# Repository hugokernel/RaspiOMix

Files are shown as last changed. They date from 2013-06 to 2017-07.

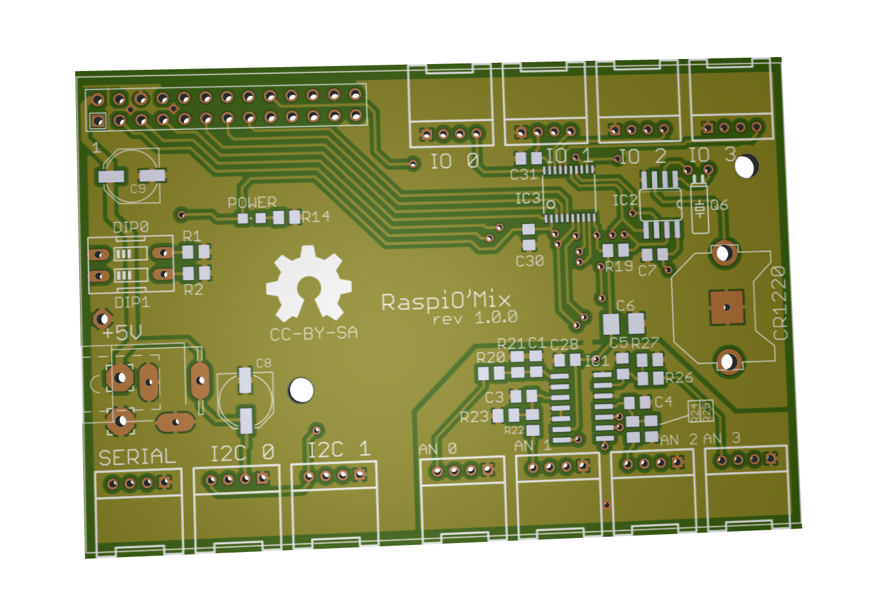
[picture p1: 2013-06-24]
export/1.0.0/images/gerber.png

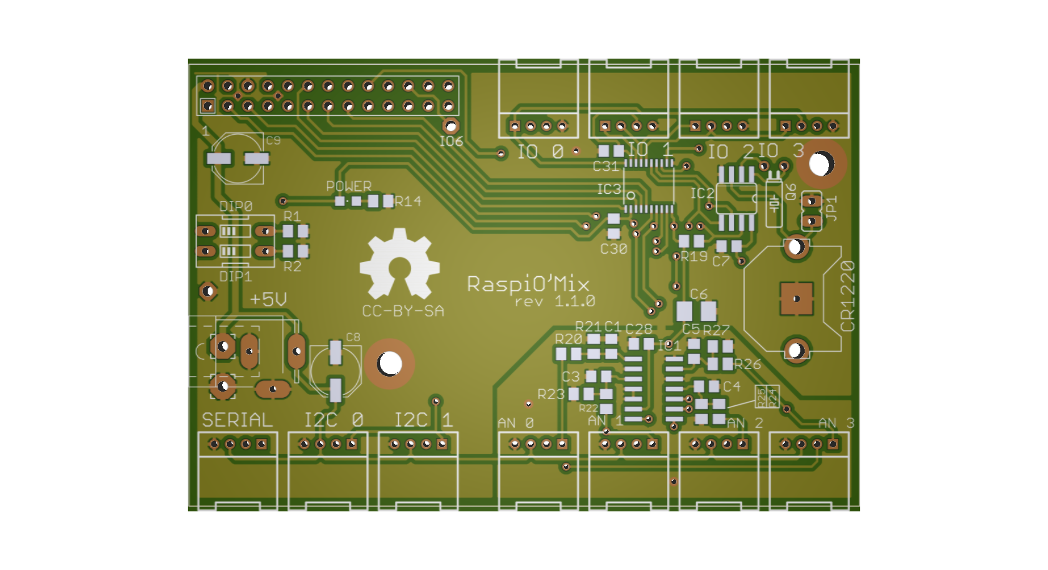
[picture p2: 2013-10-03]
export/1.1.0/images/gerber.png

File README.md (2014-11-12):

RaspiOMix
=========

A RaspberryPi board with 5V tolerance and Grove compatible.

Specifications
--------------

- 4 general 5V tolerant input / output
- 4 analog input, 0-5V, 18 bit resolution (MCP3424)
- 2 digital input via DIP switch
- Real Time Clock with battery backup (DS1307)
- 2 I2C external connector
- 1 serial external connector
- Power input via jack

Python example :

    >>> from raspiomix import Raspiomix
    >>> r = Raspiomix()
    >>> r.readRtc()
    2014-11-12T20:41:26
    >>> print(r.readAdc(0))
    [4.0669732000000005]
    >>>print(r.readAdc((0, 1, 2, 3)))
    [4.066934600000001, 0.010923800000000001, 0.08515160000000001, 0.2866822]

--

Une carte fille pour RaspberryPi avec entrées / sorties tolérantes au 5V et des connecteurs compatible Grove.

Caractéristiques
----------------

- 4 entrées / sorties tolérantes 5V
- 4 entrées analogiques, 0-5V, 18 bits de résolution (MCP3424)
- 2 entrées numériques via DIP switch
- Horloge temps réel avec batterie de sauvegarde (DS1307)
- 2 connecteurs pour I2C
- 1 connecteur pour communication série
- Alimentation via jack

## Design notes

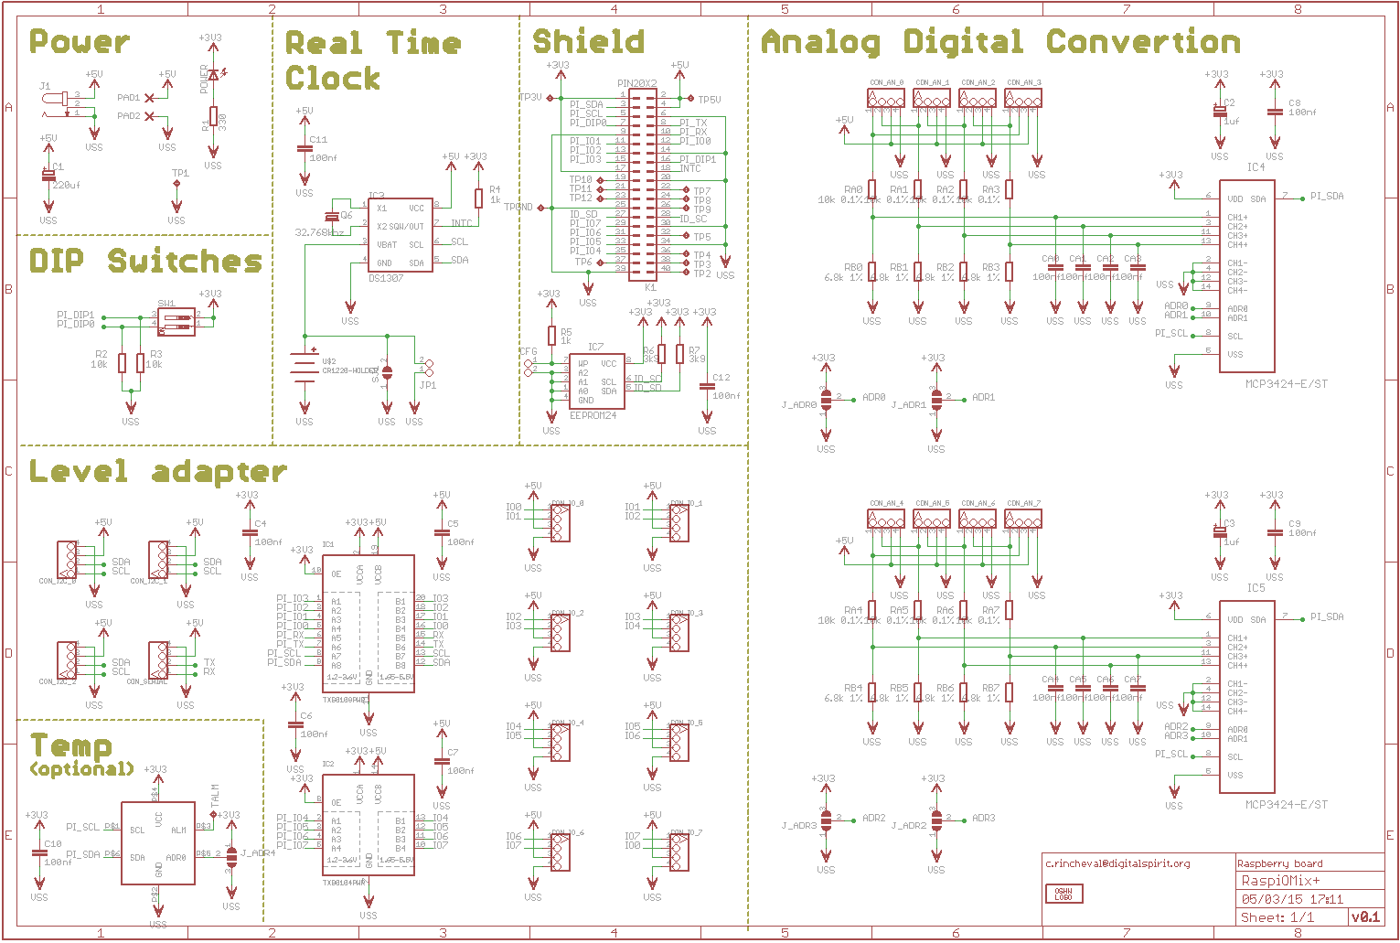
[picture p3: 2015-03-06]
export/2.0.0/images/schema.png

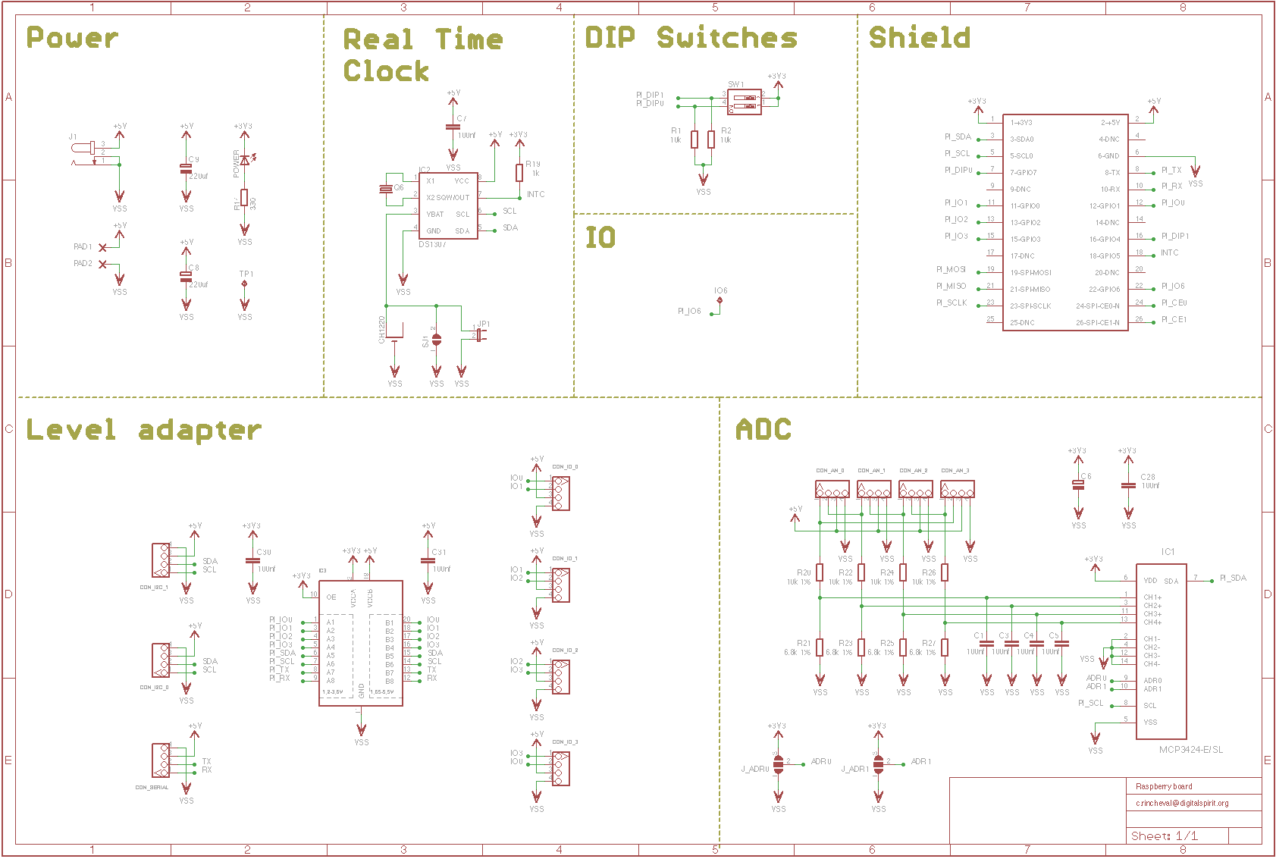
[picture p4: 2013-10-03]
export/1.1.0/images/schema.png

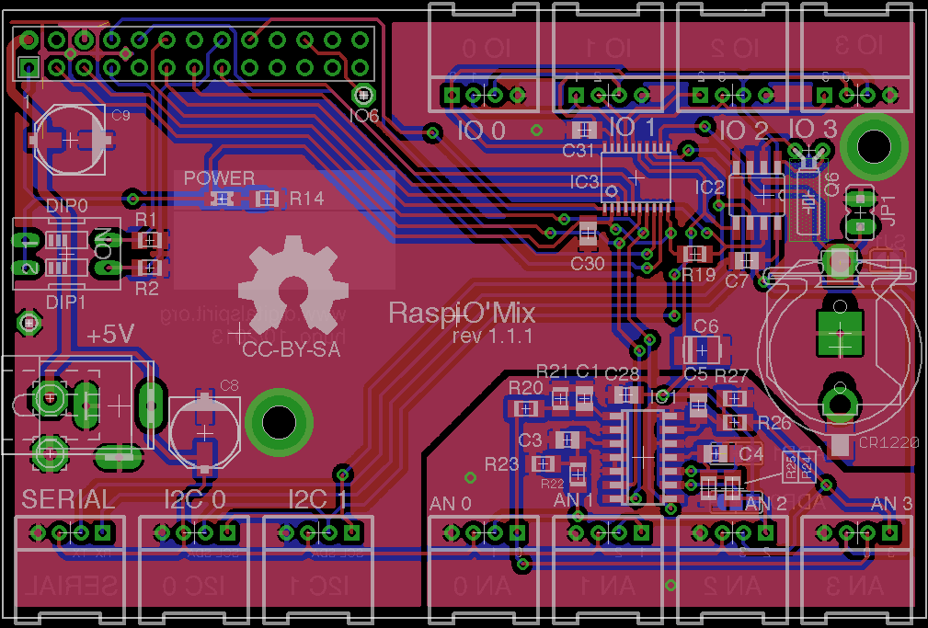
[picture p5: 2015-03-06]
export/1.1.1/images/pcb.png

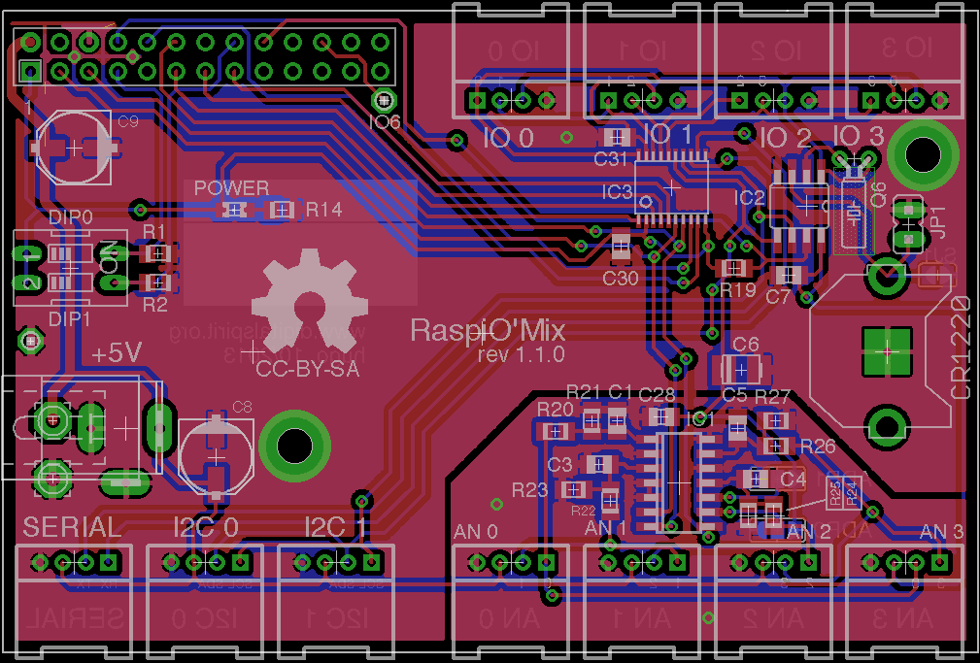
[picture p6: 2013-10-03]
export/1.1.0/images/pcb.png

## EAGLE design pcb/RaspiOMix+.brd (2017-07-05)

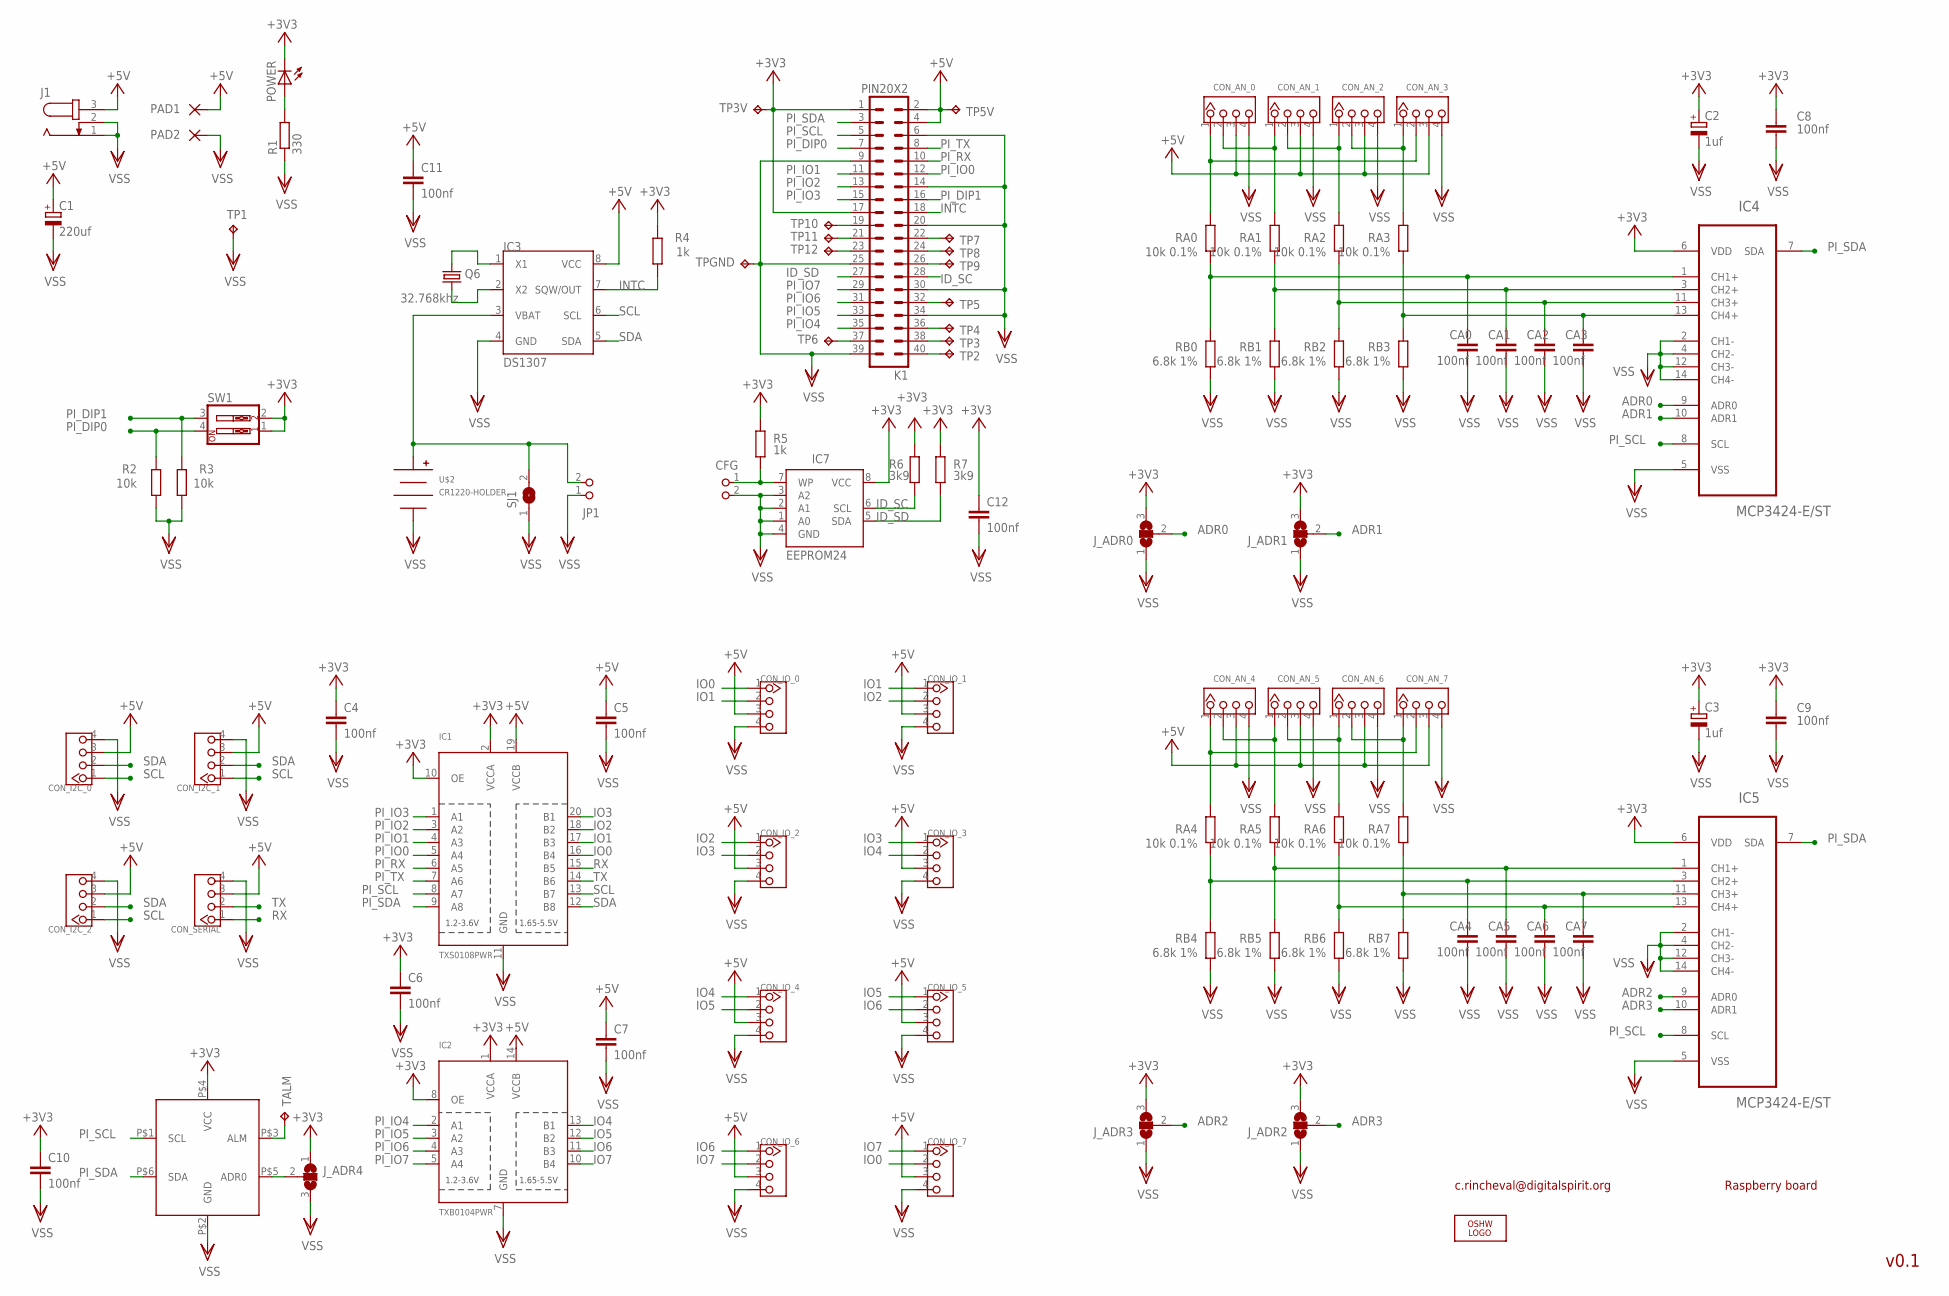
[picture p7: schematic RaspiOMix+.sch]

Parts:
C1: 220uf; PANASONIC_D
C2, C3: 1uf; B/3528-21R
C4, C5, C6, C7, C8, C9, C10, C11: 100nf; C0805
C12: 100nf; C0805K
CA0, CA1, CA2, CA3, CA4, CA5, CA6, CA7: 100nf; C0805
CFG: PIN2_100; PIN_W_2
CON_AN_0, CON_AN_1, CON_AN_2, CON_AN_3, CON_AN_4, CON_AN_5, CON_AN_6, CON_AN_7: TWIG-4P-2.0-2.0; 4P-2.0
CON_I2C_0, CON_I2C_1, CON_I2C_2: TWIG-4P-2.0-2.0; 4P-2.0
CON_IO_0, CON_IO_1, CON_IO_2, CON_IO_3, CON_IO_4, CON_IO_5, CON_IO_6, CON_IO_7: TWIG-4P-2.0-2.0; 4P-2.0
CON_SERIAL: TWIG-4P-2.0-2.0; 4P-2.0
IC1: TXS0108PWR; TSSOP20
IC2: TXB0104PWR; TSSOP14
IC3: DS1307; SOIC-8
IC4, IC5: MCP3424-E/ST; SOP65P640X120-14N
IC6: TMP101; SOT23-6
IC7: EEPROM24; SOIC8
J1: JACK-PLUG0; SPC4077
JP1: PIN2_100; PIN_W_2
J_ADR0, J_ADR1, J_ADR2, J_ADR3, J_ADR4: SJ2W; SJ_2
K1: PIN20X2; PIN_20X2
LOGO1: OSHW_LOGO_FILLX0350-NT; OSHW_FILLX350_NOTEXT
PAD1, PAD2: WIREPAD3,17/1,3; 3,17/1,3
POWER: LEDCHIPLED_0805; CHIPLED_0805
Q6: 32.768khz; TC26H
R1: 330; M0805
R2, R3: 10k; M0805
R4: 1k; M0805
R5: 1k; M0805; TOLERANCE 5%
R6, R7: 3k9; M0805; TOLERANCE 5%
RA0, RA1, RA2, RA3, RA4, RA5, RA6, RA7: 10k 0.1%; M0805
RB0, RB1, RB2, RB3, RB4, RB5, RB6, RB7: 6.8k 1%; M0805
SJ1: SJ
SW1: SW_DIP-2; EDG-02
TALM: TPTP12R; TP12R
TP1: TPPAD1-13; P1-13
TP2, TP3, TP3V, TP4, TP5, TP5V, TP6, TP7, TP8, TP9, TP10, TP11, TP12: TPTP12R; TP12R
TPGND: TPTP12R; TP12R
U$2: CR1220-HOLDER; HARWIN-CR1220

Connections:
+3V3: C2.+, C3.+, C4.1, C6.1, C8.2, C9.2, C10.1, C12.1, IC1.2 (VCCA), IC1.10 (OE), IC2.1 (VCCA), IC2.8 (OE), IC4.6 (VDD), IC5.6 (VDD), IC6.P$4 (VCC), IC7.8 (VCC), J_ADR0.3, J_ADR1.3, J_ADR2.3, J_ADR3.3, J_ADR4.1, K1.1, K1.17, POWER.C, R4.2, R5.2, R6.2, R7.2, SW1.1, SW1.2, TP3V.TP
+5V: C1.+, C5.1, C7.1, C11.1, CON_AN_0.3, CON_AN_1.3, CON_AN_2.3, CON_AN_3.3, CON_AN_4.3, CON_AN_5.3, CON_AN_6.3, CON_AN_7.3, CON_I2C_0.3, CON_I2C_1.3, CON_I2C_2.3, CON_IO_0.3, CON_IO_1.3, CON_IO_2.3, CON_IO_3.3, CON_IO_4.3, CON_IO_5.3, CON_IO_6.3, CON_IO_7.3, CON_SERIAL.3, IC1.19 (VCCB), IC2.14 (VCCB), IC3.8 (VCC), J1.3, K1.2, K1.4, PAD1.1, TP5V.TP
ADR0: IC4.9 (ADR0), J_ADR0.2
ADR1: IC4.10 (ADR1), J_ADR1.2
ADR2: IC5.9 (ADR0), J_ADR3.2
ADR3: IC5.10 (ADR1), J_ADR2.2
AN0: CON_AN_0.1, CON_AN_3.2, RA0.2
AN1: CON_AN_0.2, CON_AN_1.1, RA1.2
AN2: CON_AN_1.2, CON_AN_2.1, RA2.2
AN3: CON_AN_2.2, CON_AN_3.1, RA3.2
AN4: CON_AN_4.1, CON_AN_7.2, RA4.2
AN5: CON_AN_4.2, CON_AN_5.1, RA5.2
AN6: CON_AN_5.2, CON_AN_6.1, RA6.2
AN7: CON_AN_6.2, CON_AN_7.1, RA7.2
ID_SC: IC7.6 (SCL), K1.28, R6.1
ID_SD: IC7.5 (SDA), K1.27, R7.1
INTC: IC3.7 (SQW/OUT), K1.18, R4.1
IO0: CON_IO_0.1, CON_IO_7.2, IC1.16 (B4)
IO1: CON_IO_0.2, CON_IO_1.1, IC1.17 (B3)
IO2: CON_IO_1.2, CON_IO_2.1, IC1.18 (B2)
IO3: CON_IO_2.2, CON_IO_3.1, IC1.20 (B1)
IO4: CON_IO_3.2, CON_IO_4.1, IC2.13 (B1)
IO5: CON_IO_4.2, CON_IO_5.1, IC2.12 (B2)
IO6: CON_IO_5.2, CON_IO_6.1, IC2.11 (B3)
IO7: CON_IO_6.2, CON_IO_7.1, IC2.10 (B4)
unnamed: K1.40, TP2.TP
unnamed: K1.38, TP3.TP
unnamed: CFG.1, IC7.7 (WP), R5.1
unnamed: CA3.1, IC4.13 (CH4+), RA3.1, RB3.2
unnamed: CA2.1, IC4.11 (CH3+), RA2.1, RB2.2
unnamed: CA1.1, IC4.3 (CH2+), RA1.1, RB1.2
unnamed: CA0.1, IC4.1 (CH1+), RA0.1, RB0.2
unnamed: CA7.1, IC5.11 (CH3+), RA7.1, RB7.2
unnamed: CA6.1, IC5.13 (CH4+), RA6.1, RB6.2
unnamed: CA5.1, IC5.1 (CH1+), RA5.1, RB5.2
unnamed: CA4.1, IC5.3 (CH2+), RA4.1, RB4.2
unnamed: K1.36, TP4.TP
unnamed: K1.32, TP5.TP
unnamed: K1.37, TP6.TP
unnamed: K1.22, TP7.TP
unnamed: K1.24, TP8.TP
unnamed: K1.26, TP9.TP
unnamed: K1.19, TP10.TP
unnamed: K1.21, TP11.TP
unnamed: K1.23, TP12.TP
unnamed: IC6.P$5 (ADR0), J_ADR4.2
unnamed: IC6.P$3 (ALM), TALM.TP
unnamed: IC3.1 (X1), Q6.1
unnamed: IC3.2 (X2), Q6.2
unnamed: POWER.A, R1.2
unnamed: IC3.3 (VBAT), JP1.2, SJ1.2, U$2.POS
PI_DIP0: K1.7, R2.2, SW1.4
PI_DIP1: K1.16, R3.2, SW1.3
PI_IO0: IC1.5 (A4), K1.12
PI_IO1: IC1.4 (A3), K1.11
PI_IO2: IC1.3 (A2), K1.13
PI_IO3: IC1.1 (A1), K1.15
PI_IO4: IC2.2 (A1), K1.35
PI_IO5: IC2.3 (A2), K1.33
PI_IO6: IC2.4 (A3), K1.31
PI_IO7: IC2.5 (A4), K1.29
PI_RX: IC1.6 (A5), K1.10
PI_SCL: IC1.8 (A7), IC4.8 (SCL), IC5.8 (SCL), IC6.P$1 (SCL), K1.5
PI_SDA: IC1.9 (A8), IC4.7 (SDA), IC5.7 (SDA), IC6.P$6 (SDA), K1.3
PI_TX: IC1.7 (A6), K1.8
RX: CON_SERIAL.1, IC1.15 (B5)
SCL: CON_I2C_0.1, CON_I2C_1.1, CON_I2C_2.1, IC1.13 (B7), IC3.6 (SCL)
SDA: CON_I2C_0.2, CON_I2C_1.2, CON_I2C_2.2, IC1.12 (B8), IC3.5 (SDA)
TX: CON_SERIAL.2, IC1.14 (B6)
VSS: C1.-, C2.-, C3.-, C4.2, C5.2, C6.2, C7.2, C8.1, C9.1, C10.2, C11.2, C12.2, CA0.2, CA1.2, CA2.2, CA3.2, CA4.2, CA5.2, CA6.2, CA7.2, CFG.2, CON_AN_0.4, CON_AN_1.4, CON_AN_2.4, CON_AN_3.4, CON_AN_4.4, CON_AN_5.4, CON_AN_6.4, CON_AN_7.4, CON_I2C_0.4, CON_I2C_1.4, CON_I2C_2.4, CON_IO_0.4, CON_IO_1.4, CON_IO_2.4, CON_IO_3.4, CON_IO_4.4, CON_IO_5.4, CON_IO_6.4, CON_IO_7.4, CON_SERIAL.4, IC1.11 (GND), IC2.7 (GND), IC3.4 (GND), IC4.2 (CH1-), IC4.4 (CH2-), IC4.5 (VSS), IC4.12 (CH3-), IC4.14 (CH4-), IC5.2 (CH1-), IC5.4 (CH2-), IC5.5 (VSS), IC5.12 (CH3-), IC5.14 (CH4-), IC6.P$2 (GND), IC7.1 (A0), IC7.2 (A1), IC7.3 (A2), IC7.4 (GND), J1.1, J1.2, JP1.1, J_ADR0.1, J_ADR1.1, J_ADR2.1, J_ADR3.1, J_ADR4.3, K1.6, K1.9, K1.14, K1.20, K1.25, K1.30, K1.34, K1.39, PAD2.1, R1.1, R2.1, R3.1, RB0.1, RB1.1, RB2.1, RB3.1, RB4.1, RB5.1, RB6.1, RB7.1, SJ1.1, TP1.TP, TPGND.TP, U$2.NEG

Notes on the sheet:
v0.1
c.rincheval@digitalspirit.org
Raspberry board

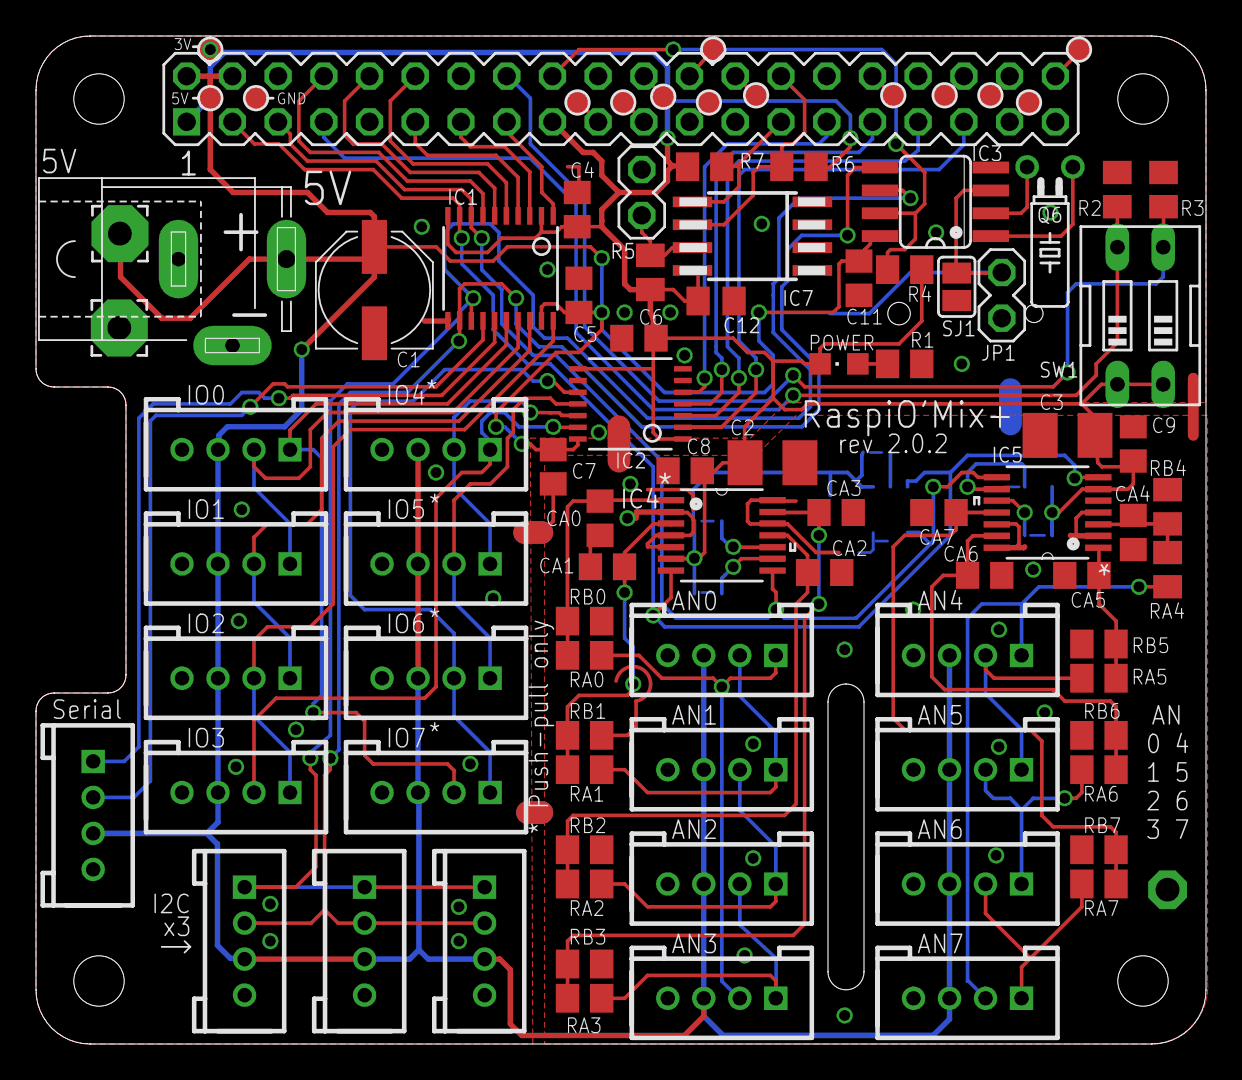
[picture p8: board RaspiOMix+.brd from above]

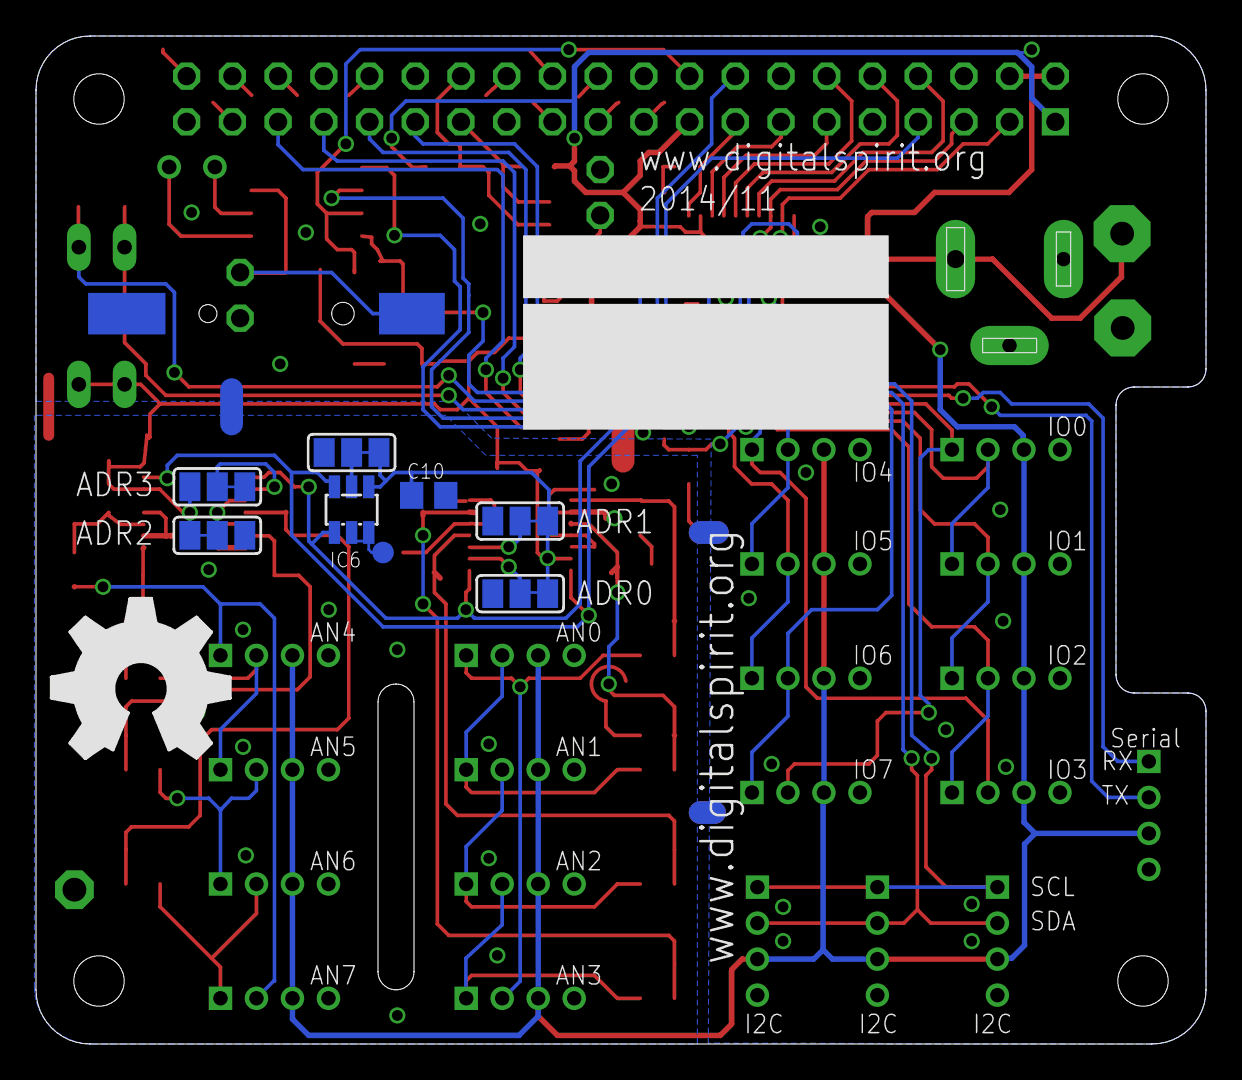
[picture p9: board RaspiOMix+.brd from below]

Board: 2 copper layers, 65.0 x 56.0 mm, 103 parts (10 on the bottom side), 70 nets.

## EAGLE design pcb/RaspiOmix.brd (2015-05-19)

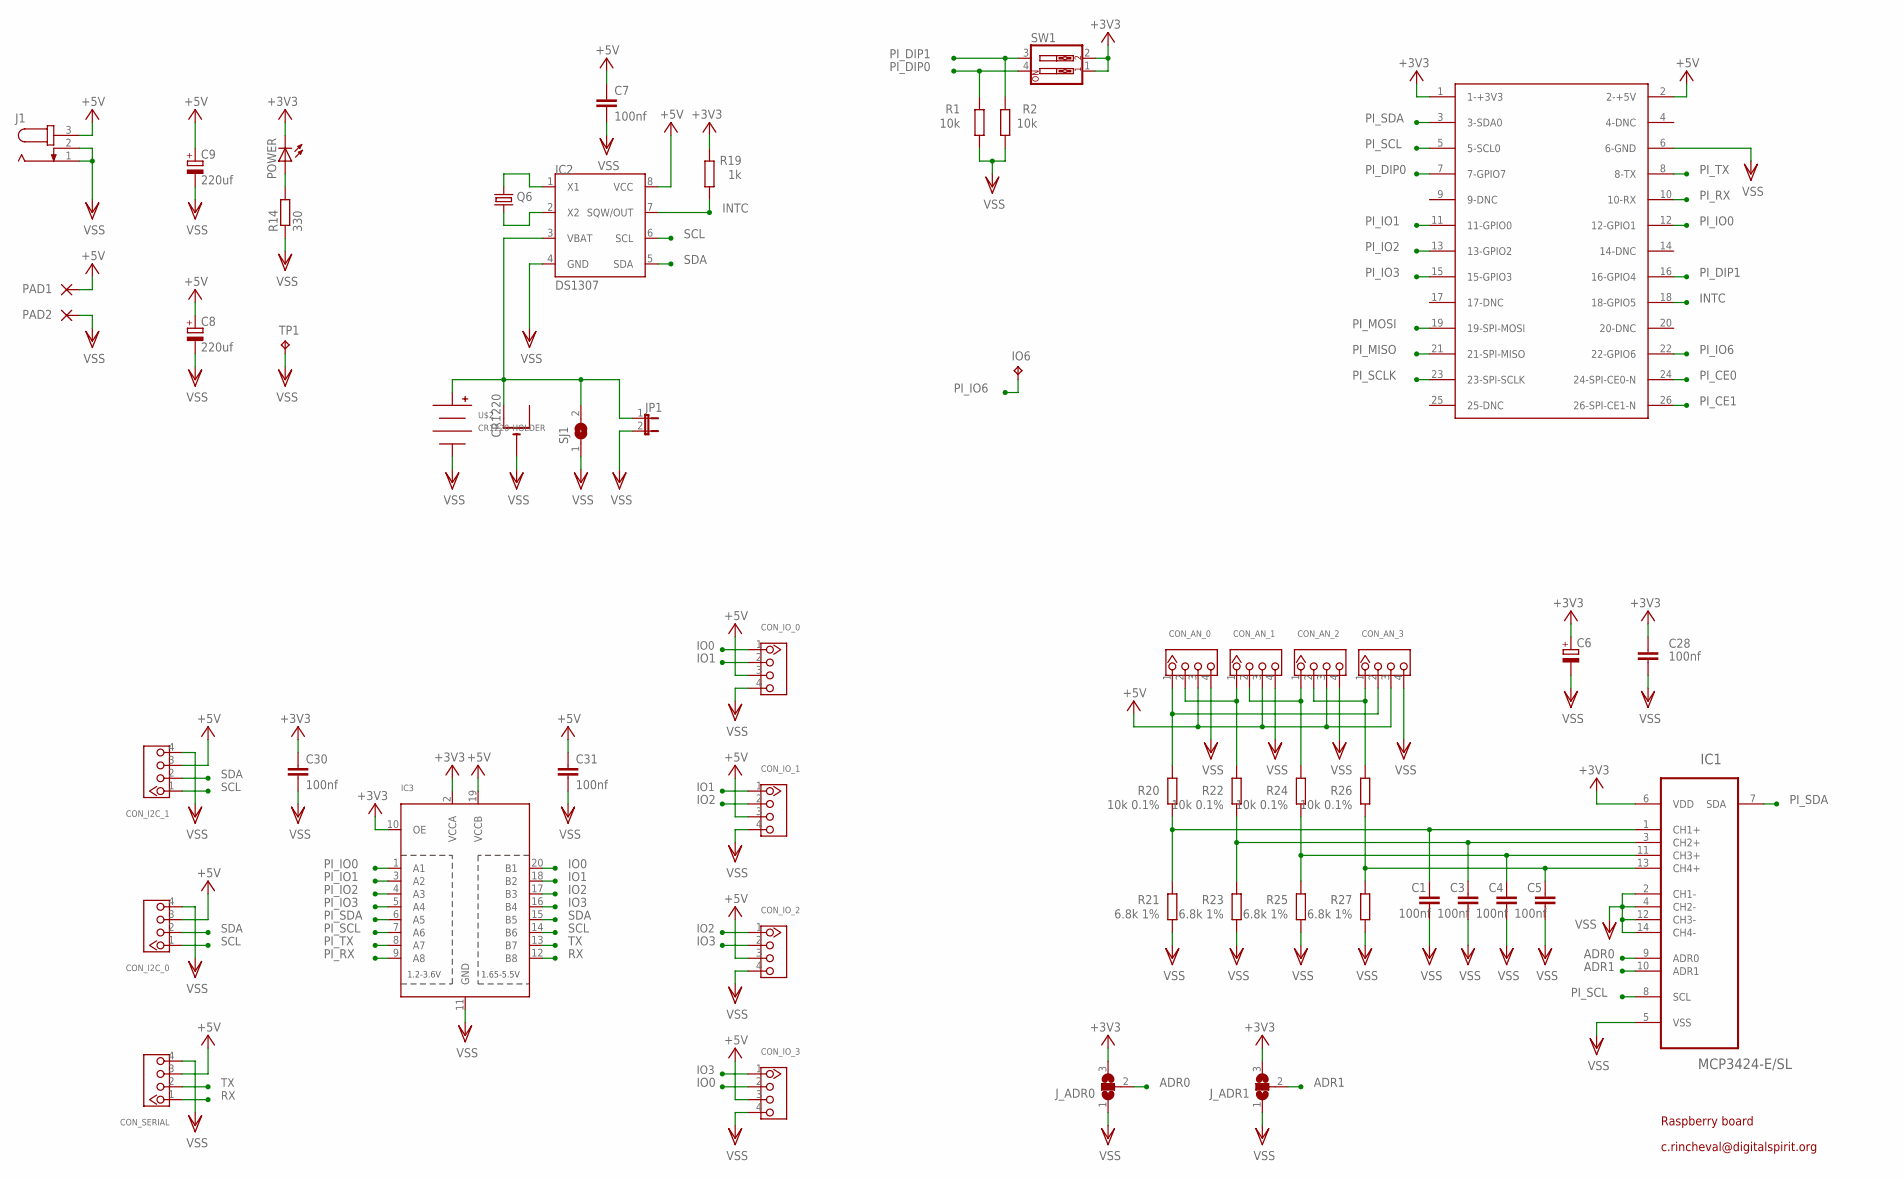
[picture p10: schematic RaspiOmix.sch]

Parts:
C1, C3, C4, C5, C7, C28, C30, C31: 100nf; C0805
C6: CPOL-EUB/3528-21R; B/3528-21R
C8, C9: 220uf; PANASONIC_D
CON_AN_0, CON_AN_1, CON_AN_2, CON_AN_3: TWIG-4P-2.0'90D'; 4P-2.0-90D
CON_I2C_0, CON_I2C_1: TWIG-4P-2.0'90D'; 4P-2.0-90D
CON_IO_0, CON_IO_1, CON_IO_2, CON_IO_3: TWIG-4P-2.0'90D'; 4P-2.0-90D
CON_SERIAL: TWIG-4P-2.0'90D'; 4P-2.0-90D
CR1220: CR1220THM; CR1220-THM
IC1: MCP3424-E/SL; SOIC-14
IC2: DS1307; SOIC-8
IC3: TXB0108PWR; TSSOP20
IO6: TPPAD1-13; P1-13
J1: JACK-PLUG0; SPC4077
JP1: JP1E; JP1
J_ADR0, J_ADR1: SJ2W; SJ_2
PAD1, PAD2: WIREPAD3,17/1,3; 3,17/1,3
POWER: LEDCHIPLED_0805; CHIPLED_0805
Q6: CRYSTALTC26H; TC26H
R1, R2: 10k; M0805
R14: 330; M0805
R19: 1k; M0805
R20, R22, R24, R26: 10k 0.1%; M0805
R21, R23, R25, R27: 6.8k 1%; M0805
SJ1: SJ
SW1: SW_DIP-2; EDG-02
TP1: TPPAD1-13; P1-13
U$2: CR1220-HOLDER; HARWIN-CR1220
U$3: RASPBERRY-PILIGHT-HOLE; RASPBERRY-PI-LIGHT-HOLE

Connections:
+3V3: C6.+, C28.2, C30.1, IC1.6 (VDD), IC3.2 (VCCA), IC3.10 (OE), J_ADR0.3, J_ADR1.3, POWER.C, R19.2, SW1.1, SW1.2, U$3.1 (1-+3V3)
+5V: C7.1, C8.+, C9.+, C31.1, CON_AN_0.3, CON_AN_1.3, CON_AN_2.3, CON_AN_3.3, CON_I2C_0.3, CON_I2C_1.3, CON_IO_0.3, CON_IO_1.3, CON_IO_2.3, CON_IO_3.3, CON_SERIAL.3, IC2.8 (VCC), IC3.19 (VCCB), J1.3, PAD1.1, U$3.2 (2-+5V)
ADR0: IC1.9 (ADR0), J_ADR0.2
ADR1: IC1.10 (ADR1), J_ADR1.2
AN0: CON_AN_0.1, CON_AN_3.2, R20.2
AN1: CON_AN_0.2, CON_AN_1.1, R22.2
AN2: CON_AN_1.2, CON_AN_2.1, R24.2
AN3: CON_AN_2.2, CON_AN_3.1, R26.2
INTC: IC2.7 (SQW/OUT), R19.1, U$3.18 (18-GPIO5)
IO0: CON_IO_0.1, CON_IO_3.2, IC3.20 (B1)
IO1: CON_IO_0.2, CON_IO_1.1, IC3.18 (B2)
IO2: CON_IO_1.2, CON_IO_2.1, IC3.17 (B3)
IO3: CON_IO_2.2, CON_IO_3.1, IC3.16 (B4)
unnamed: C5.1, IC1.13 (CH4+), R26.1, R27.2
unnamed: C4.1, IC1.11 (CH3+), R24.1, R25.2
unnamed: C3.1, IC1.3 (CH2+), R22.1, R23.2
unnamed: C1.1, IC1.1 (CH1+), R20.1, R21.2
unnamed: IC2.1 (X1), Q6.1
unnamed: IC2.2 (X2), Q6.2
unnamed: POWER.A, R14.2
unnamed: CR1220.+1 (+), IC2.3 (VBAT), JP1.1, SJ1.2, U$2.POS
PI_CE0: U$3.24 (24-SPI-CE0-N)
PI_CE1: U$3.26 (26-SPI-CE1-N)
PI_DIP0: R1.2, SW1.4, U$3.7 (7-GPIO7)
PI_DIP1: R2.2, SW1.3, U$3.16 (16-GPIO4)
PI_IO0: IC3.1 (A1), U$3.12 (12-GPIO1)
PI_IO1: IC3.3 (A2), U$3.11 (11-GPIO0)
PI_IO2: IC3.4 (A3), U$3.13 (13-GPIO2)
PI_IO3: IC3.5 (A4), U$3.15 (15-GPIO3)
PI_IO6: IO6.TP, U$3.22 (22-GPIO6)
PI_MISO: U$3.21 (21-SPI-MISO)
PI_MOSI: U$3.19 (19-SPI-MOSI)
PI_RX: IC3.9 (A8), U$3.10 (10-RX)
PI_SCL: IC1.8 (SCL), IC3.7 (A6), U$3.5 (5-SCL0)
PI_SCLK: U$3.23 (23-SPI-SCLK)
PI_SDA: IC1.7 (SDA), IC3.6 (A5), U$3.3 (3-SDA0)
PI_TX: IC3.8 (A7), U$3.8 (8-TX)
RX: CON_SERIAL.1, IC3.12 (B8)
SCL: CON_I2C_0.1, CON_I2C_1.1, IC2.6 (SCL), IC3.14 (B6)
SDA: CON_I2C_0.2, CON_I2C_1.2, IC2.5 (SDA), IC3.15 (B5)
TX: CON_SERIAL.2, IC3.13 (B7)
VSS: C1.2, C3.2, C4.2, C5.2, C6.-, C7.2, C8.-, C9.-, C28.1, C30.2, C31.2, CON_AN_0.4, CON_AN_1.4, CON_AN_2.4, CON_AN_3.4, CON_I2C_0.4, CON_I2C_1.4, CON_IO_0.4, CON_IO_1.4, CON_IO_2.4, CON_IO_3.4, CON_SERIAL.4, CR1220.-, IC1.2 (CH1-), IC1.4 (CH2-), IC1.5 (VSS), IC1.12 (CH3-), IC1.14 (CH4-), IC2.4 (GND), IC3.11 (GND), J1.1, J1.2, JP1.2, J_ADR0.1, J_ADR1.1, PAD2.1, R1.1, R2.1, R14.1, R21.1, R23.1, R25.1, R27.1, SJ1.1, TP1.TP, U$2.NEG, U$3.6 (6-GND)

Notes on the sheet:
c.rincheval@digitalspirit.org
Raspberry board

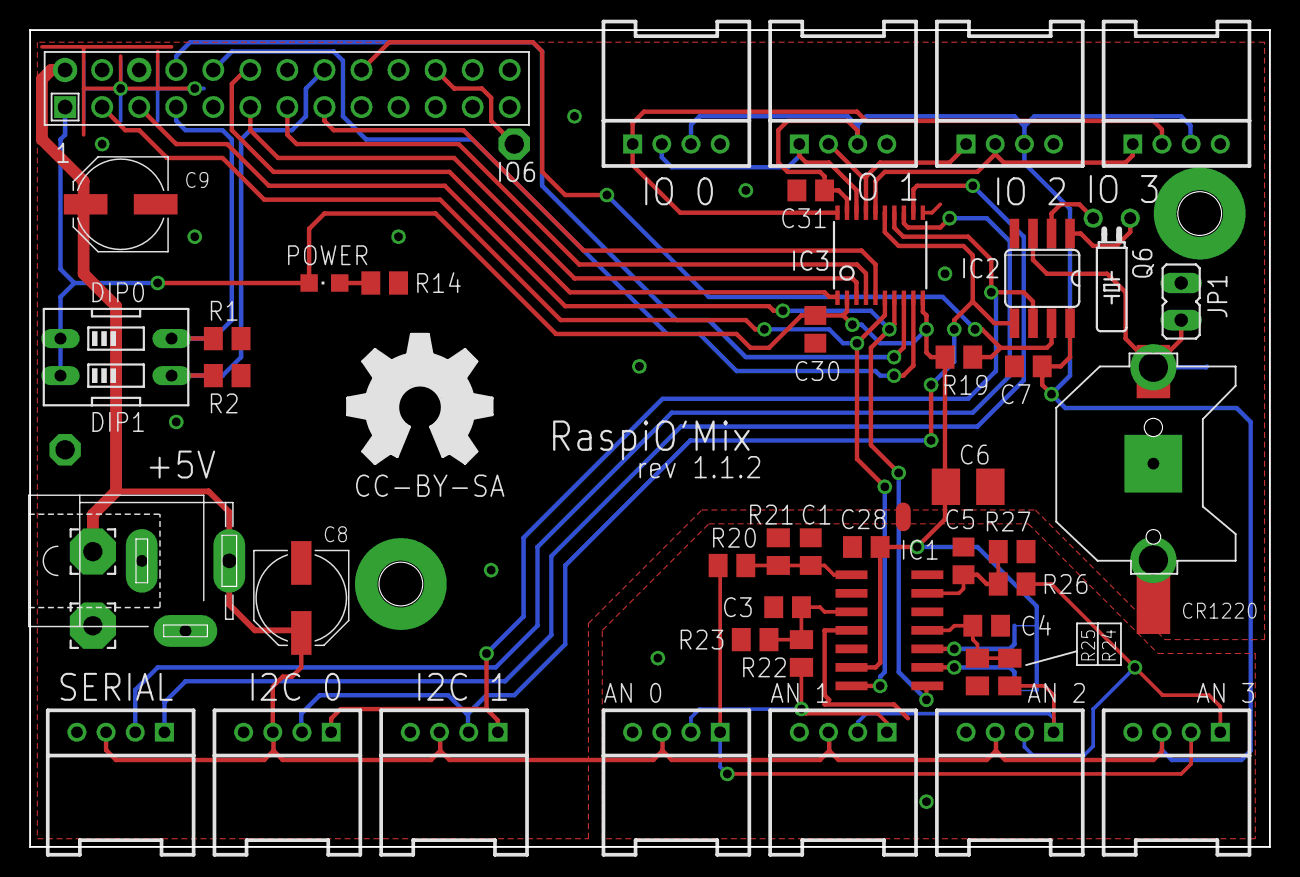
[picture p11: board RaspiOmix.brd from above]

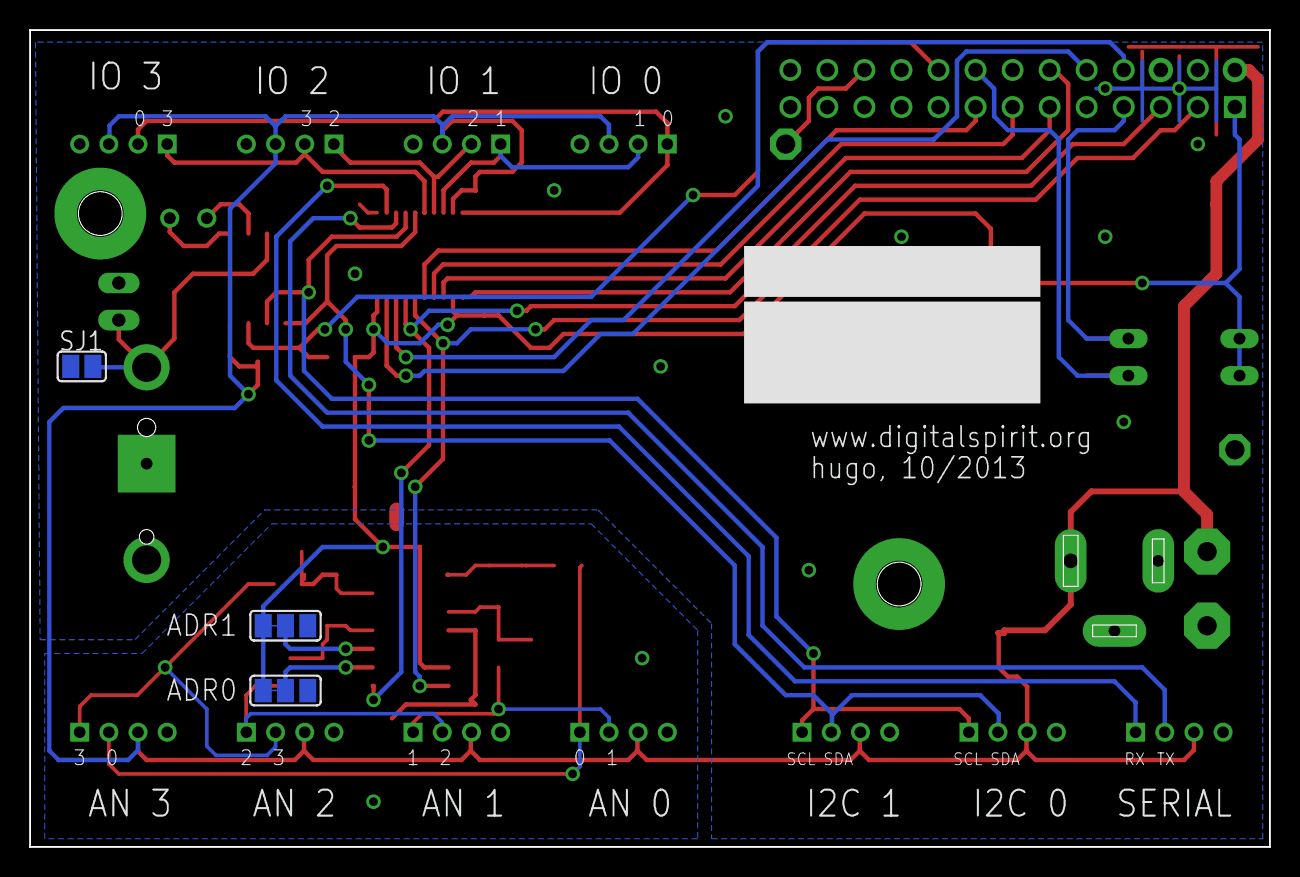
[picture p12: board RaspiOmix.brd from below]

Board: 2 copper layers, 85.0 x 56.0 mm, 53 parts (3 on the bottom side), 37 nets.

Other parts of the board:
U$1: OSHW_FILLX350_NOTEXT

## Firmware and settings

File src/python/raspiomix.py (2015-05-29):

#!/usr/bin/python

class Raspiomix_Base:

    """
    RaspiOMix version 1.0.1
    IO0 = 7
    IO1 = 11
    IO2 = 13
    IO3 = 15

    DIP0 = 12
    DIP1 = 16
    """

    """
    RaspiOMix version 1.1.0
    """

    IO0 = 12
    IO1 = 11
    IO2 = 13
    IO3 = 15

    DIP0 = 7
    DIP1 = 16

    I2C_ADC_ADDRESS = 0x6E
    I2C_ADC0_ADDRESS = I2C_ADC_ADDRESS

    I2C_RTC_ADDRESS = 0x68

    ADC_CHANNELS = [ 0x9C, 0xBC, 0xDC, 0xFC ]
    ADC0_CHANNELS = ADC_CHANNELS

    # RaspiO'Mix+
    I2C_ADC1_ADDRESS = 0x6A
    ADC1_CHANNELS = [ 0xBC, 0x9C, 0xFC, 0xDC ]

    IO4 = 35
    IO5 = 33
    IO6 = 31
    IO7 = 29

    SERIAL_TX = 8
    SERIAL_RX = 10

    DEVICE = '/dev/ttyAMA0'

class Raspiomix(Raspiomix_Base):

    i2c = None
    i2c_bus = 0

    ADC_MULTIPLIER = 0.0000386

    def __init__(self):
        import re
        import smbus

        # detect i2C port number and assign to i2c_bus
        for line in open('/proc/cpuinfo').readlines():
            m = re.match('(.*?)\s*:\s*(.*)', line)
            if m:
                (name, value) = (m.group(1), m.group(2))
                if name == "Revision":
                    if value [-4:] in ('0002', '0003'):
                        self.i2c_bus = 0
                    else:
                        self.i2c_bus = 1
                    break

        self.i2c = smbus.SMBus(self.i2c_bus);

    def isPlus(self):
        """Detect if board si a RaspiO'Mix+
        """
        try: 
            self.i2c.read_i2c_block_data(self.I2C_ADC1_ADDRESS, 0) 
            return True
        except IOError:
            return False

    def readAdc(self, channels=(0, 1, 2, 3)):
        """Read analog channel
        """

        def format(h, m, l):
            # shift bits to product result
            t = ((h & 0b00000001) << 16) | (m << 8) | l
            # check if positive or negative number and invert if needed
            if (h > 128):
                t = ~(0x020000 - t)
            return t * self.ADC_MULTIPLIER

        def read(i2c_address, channel):
            while True:
                data = self.i2c.read_i2c_block_data(i2c_address, channel)
                h, m, l, s = data[0:4]
                if not (s & 128):
                    break
            return format(h, m, l)

        out = []
        for channel in ((channels,) if type(channels) == int else channels):
            i2c_address = self.I2C_ADC0_ADDRESS if channel < 4 else self.I2C_ADC1_ADDRESS
            channel = self.ADC0_CHANNELS[channel] if channel < 4 else self.ADC1_CHANNELS[channel - 4]

            out.append(read(i2c_address, channel))

        return out[0] if type(channels) == int else out

    def readRtc(self):
        """Read rtc clock
        """

        try:
            data = self.i2c.read_i2c_block_data(self.I2C_RTC_ADDRESS, 0x00)
        except IOError as e:
            raise IOError(str(e) + " (Maybe rtc_ds1307 module is loaded ?)")

        def bcd_to_int(bcd):
            """2x4bit BCD to integer
            """
            out = 0
            for d in (bcd >> 4, bcd):
                for p in (1, 2, 4 ,8):
                    if d & 1:
                        out += p
                    d >>= 1
                out *= 10
            return out / 10

        data[0] = bcd_to_int(data[0])
        data[1] = bcd_to_int(data[1])

        d = (data[2])
        if (d == 0x64):
            d = 0x40
        data[2] = bcd_to_int(d & 0x3F)

        for i, item in enumerate(data[3:7]):
            data[i + 3] = bcd_to_int(item)

        return '20%02d-%02d-%02dT%02d:%02d:%02d' % (data[6], data[5], data[4], data[2], data[1], data[0])

if __name__ == '__main__':
    r = Raspiomix()
    print(r.readRtc())
    print(r.readAdc(0))
    print(r.readAdc((0, 1, 2, 3)))

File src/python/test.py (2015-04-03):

#!/usr/bin/python

import curses
import random
import string
import smbus
from copy import copy
from time import sleep

from raspiomix import Raspiomix
import serial
import RPi.GPIO as GPIO

raspi = Raspiomix()
IS_PLUS = raspi.isPlus()

info = None

GPIOS = (
    Raspiomix.IO0,
    Raspiomix.IO1,
    Raspiomix.IO2,
    Raspiomix.IO3,
)

if IS_PLUS:
    GPIOS += (
        Raspiomix.IO4,
        Raspiomix.IO5,
        Raspiomix.IO6,
        Raspiomix.IO7,
    )

GPIOS += (
    Raspiomix.DIP0,
    Raspiomix.DIP1
)

'''
 Channel #0 : [========================================================================================] 5.42
 Channel #1 : [=                                                                                       ] 0.01
 Channel #2 : [===                                                                                     ] 0.12
 Channel #3 : [=======                                                                                 ] 0.38
'''

GPIO.setmode(GPIO.BOARD)
GPIO.setwarnings(False)

'''
import time
for index in range(len(GPIOS)):
    GPIO.setup(GPIOS[index], GPIO.IN)
while True:
    current = [ 0 ] * len(GPIOS)
    for index in range(len(GPIOS)):
        current[index] = GPIO.input(GPIOS[index])
    print current
    time.sleep(1)
'''

def fillwin(w, c):
    y, x = w.getmaxyx()
    s = c * (x - 1)
    for l in range(y):
        w.addstr(l, 0, s)

def debug(string):
    db = curses.newwin(3, len(string) + 2, 5, 5)
    db.border()
    db.addstr(1, 1, string)
    db.touchwin()
    db.refresh()
    #db.getch()
    sleep(1)

class Window:
    pad = None
    size = []
    pos = []

    def refresh(self):
        self.pad.refresh(*self.pos)

    def clear(self):
        y, x = self.pad.getmaxyx()
        s = ' ' * (x - 2)
        for l in range(1, y):
            self.pad.addstr(l, 1, s)

class Input(Window):

    INPUT = 'i'
    OUTPUT = 'o'

    mode = INPUT
    output_level = 0

    STATE_LOW = '0'
    STATE_HIGH = '1'

    def __init__(self, height, width, pos):
        self.pos = pos
        self.pad = curses.newpad(height, width)
        self.pad.border()
        self.pad.addstr(0, 2, "Input / Output", curses.A_BOLD)
        self.pad.addstr(9, 3, "Press i or o key to switch In / Out")
        self.reset()

    def reset(self):
        self.last = [ -1 ] * len(GPIOS)
        self.current = [ 0 ] * len(GPIOS)

    def update(self, key = None):

        if key:
            if key == ord('i'):
                self.mode = self.INPUT
                self.clear()
                self.reset()
            if key == ord('o'):
                self.mode = self.OUTPUT
                self.clear()
                self.reset()

        # Clean line
        self.pad.addstr(2, 3, "           ")
        if self.mode == self.INPUT:

            for io in GPIOS:
                GPIO.setup(io, GPIO.IN)

            self.pad.addstr(2, 3, "Input mode", curses.A_UNDERLINE)

            #self.current = random.sample(range(5), 4)
            for index in range(len(GPIOS)):
                self.current[index] = GPIO.input(GPIOS[index])

            if self.last != self.current:
                self.pad.addstr(4, 3, "IO: ")
                #for channel in range(0, 4):
                for channel in range(len(GPIOS) - 2):
                    status = self.STATE_HIGH if self.current[channel] else self.STATE_LOW + ' '
                    self.pad.addstr(4, 8 + (channel * 5), "%i:%s" % (channel, status))

                self.pad.addstr(6, 3, "DIP:")
                i = 0
                for channel in range(len(GPIOS) - 2, len(GPIOS)):
                    status = self.STATE_HIGH if self.current[channel] else self.STATE_LOW + ' '
                    self.pad.addstr(6, 8 + (i * 5), "%i:%s" % (i, status))
                    i += 1
                self.last = copy(self.current)
            self.pad.refresh(*self.pos)
        elif self.mode == self.OUTPUT:

            for io in GPIOS:
                GPIO.setup(io, GPIO.OUT)

            self.pad.addstr(2, 3, "Output mode", curses.A_UNDERLINE)
            #for channel in range(0, 4):
            for channel in range(len(GPIOS) - 2):
                GPIO.output(GPIOS[channel], GPIO.HIGH if self.output_level else GPIO.LOW)
                status = self.STATE_HIGH if self.output_level else self.STATE_LOW + ' '
                information("status:%s, %i" % (status, self.output_level))
                self.pad.addstr(4 + channel, 3, "Channel #%i : %s" % (channel, status))

            self.output_level = 0 if self.output_level else 1
            self.pad.refresh(*self.pos)

class Analog(Window):

    last = [ -1 ] * 8
    current = [ 0 ] * 8

    MAX_VALUE = 5.0

    ADC_COUNT = 8 if IS_PLUS else 4

    def __init__(self, height, width, pos):
        self.pos = pos
        self.size = [ height, width ]
        self.pad = curses.newpad(height, width)
        self.pad.border()
        self.pad.addstr(0, 2, "Analog", curses.A_BOLD)

    def update(self, key = None):
        self.current = raspi.readAdc(range(self.ADC_COUNT))

        width = self.size[1]

        size = self.pad.getmaxyx()
        offset = int(((size[0] - 2) / 2) - 1)

        if self.last != self.current:
            for channel in range(self.ADC_COUNT):
                title = "Channel #%i : [%s] %0.2f   "

                bar = ''
                iteration = self.MAX_VALUE / (width - len(title) - 5)
                for i in range(0, width - len(title) - 3):
                    bar += ' ' if (round(self.current[channel], 2) == 0 or i * iteration > self.current[channel]) else '='

                self.pad.addstr(offset + channel, 3, title % (channel, bar, self.current[channel]))

            self.last = copy(self.current)
            self.pad.refresh(*self.pos)
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

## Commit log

2013-06-14 Small modif !
    [RaspiOmix.brd, RaspiOmix.sch]
2013-06-14 Added C6
    [RaspiOmix.brd, RaspiOmix.sch]
2013-06-24 Version avec Mosfet
    [RaspiOmix.brd, RaspiOmix.sch]
2013-06-24 Version 1.0.0
    [RaspiOmix.GBL, RaspiOmix.GBO, RaspiOmix.GBP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]
2013-06-24 Version 1.0.1
    Hole size modification
    [RaspiOmix.GBL, RaspiOmix.GBO, RaspiOmix.GBP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]
2013-07-22 PCB 1.0.8
    - Inverse grove connector
    - Hole connector linked to VSS
    [RaspiOmix.brd, RaspiOmix.sch]
2013-07-28 Move C9 label
    [RaspiOmix.brd, RaspiOmix.sch]
2013-07-28 Petite modif
    [RaspiOmix.brd]
2013-09-13 Adds simple tests scripts in python and ruby
    curses-less python analog test script
    Ruby analog test script
    Boths scripts uses the i2c kenel interface.
2013-09-13 Fixes i2c address constant
    Changed ADC_I2C_ADDRESS to I2C_ADC_ADDRESS as per raspiomix.py
2013-10-03 PCB 1.1.1
    [RaspiOmix.GBL, RaspiOmix.GBO, RaspiOmix.GBP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]
2014-11-12 New RaspiO'Mix+ hat
    Schema + PCB in progress…
    [RaspiOMix+.brd, RaspiOMix+.sch, RaspiOmix.brd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]
2014-11-12 New Python lib
    Embed i2c methods (adc, rtc) in lib
2014-11-19 Routage PCB
    [RaspiOMix+.brd, RaspiOMix+.sch, RaspiOmix.brd]
2014-12-02 RaspiO'Mix rev 1.0.0
    [RaspiOMix+.brd, RaspiOMix+.sch]
2015-03-02 RaspiO'Mix+
    Modif
    [RaspiOMix+.brd, RaspiOMix+.sch]
2015-03-06 RaspiO'Mix+ -> Pcb 2.0.0
    New RaspiO’Mix+ pcbs version is 2.0.0.
    [RaspiOMix+.GBL, RaspiOMix+.GBO, RaspiOMix+.GBP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]
2015-03-06 Version 1.1.1 modification
    [RaspiOmix.GBL, RaspiOmix.GTO, RaspiOmix.GTP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]
2017-07-05 PCB Version 2.0.2
    [RaspiOMix+.GBL, RaspiOMix+.GBO, RaspiOMix+.GBP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]

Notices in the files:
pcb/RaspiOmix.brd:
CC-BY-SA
